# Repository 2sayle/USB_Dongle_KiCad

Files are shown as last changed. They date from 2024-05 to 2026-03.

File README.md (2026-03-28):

# USB Dongle (KiCad project)

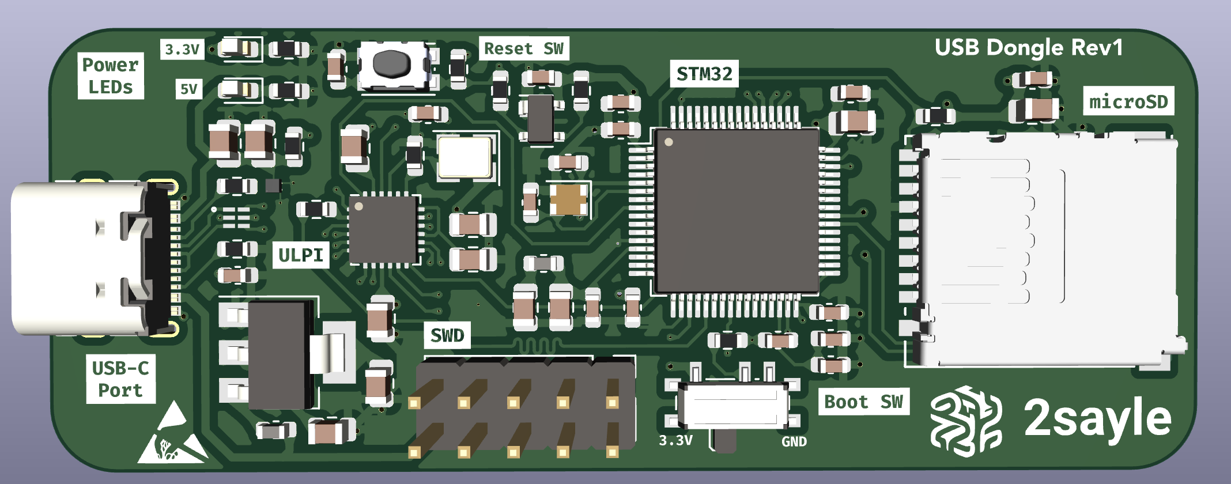
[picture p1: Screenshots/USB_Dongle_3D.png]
PCB view


KiCad project to create a custom USB-C key with mass storage and a microSD connector.
Find all the KiCad schematics and layout files.
Libraries containing custom footprints and symbols are available in ./Libraries folder.

## Hardware

- USB-C connector
- USB 2.0 High Speed Interface (through ULPI)
- STM32F730R8T microcontroller
- MicroSD connector
- Power LEDs
- GPIOs for SWD (Serial Wire Debug)

## Requirements

List any software requirements or dependencies needed to use or modify the project. For a KiCad project, this would include:

- KiCad EDA Suite version 7.0.2

## Installation

```
git clone https://github.com/2sayle/USB_Dongle_KiCad.git
```

## Usage

Explain how to use the project, with examples and screenshots if applicable.

## Documentation

Links to additional documentation for the project, such as a user manual or technical specifications.
- [STM32F730 Reference Manual](https://www.st.com/resource/en/reference_manual/rm0431-stm32f72xxx-and-stm32f73xxx-advanced-armbased-32bit-mcus-stmicroelectronics.pdf)
- [STM32F730R8 Datasheet](https://www.st.com/resource/en/datasheet/stm32f730i8.pdf)
- [ULPI Interface](http://ww1.microchip.com/downloads/en/DeviceDoc/334x.pdf)
- [USB ESD Protection](https://www.st.com/resource/en/datasheet/usbulc6-2m6.pdf)

Note: Datasheets are also available by selecting a component and pressing 'D' key, in KiCad schematics editor.

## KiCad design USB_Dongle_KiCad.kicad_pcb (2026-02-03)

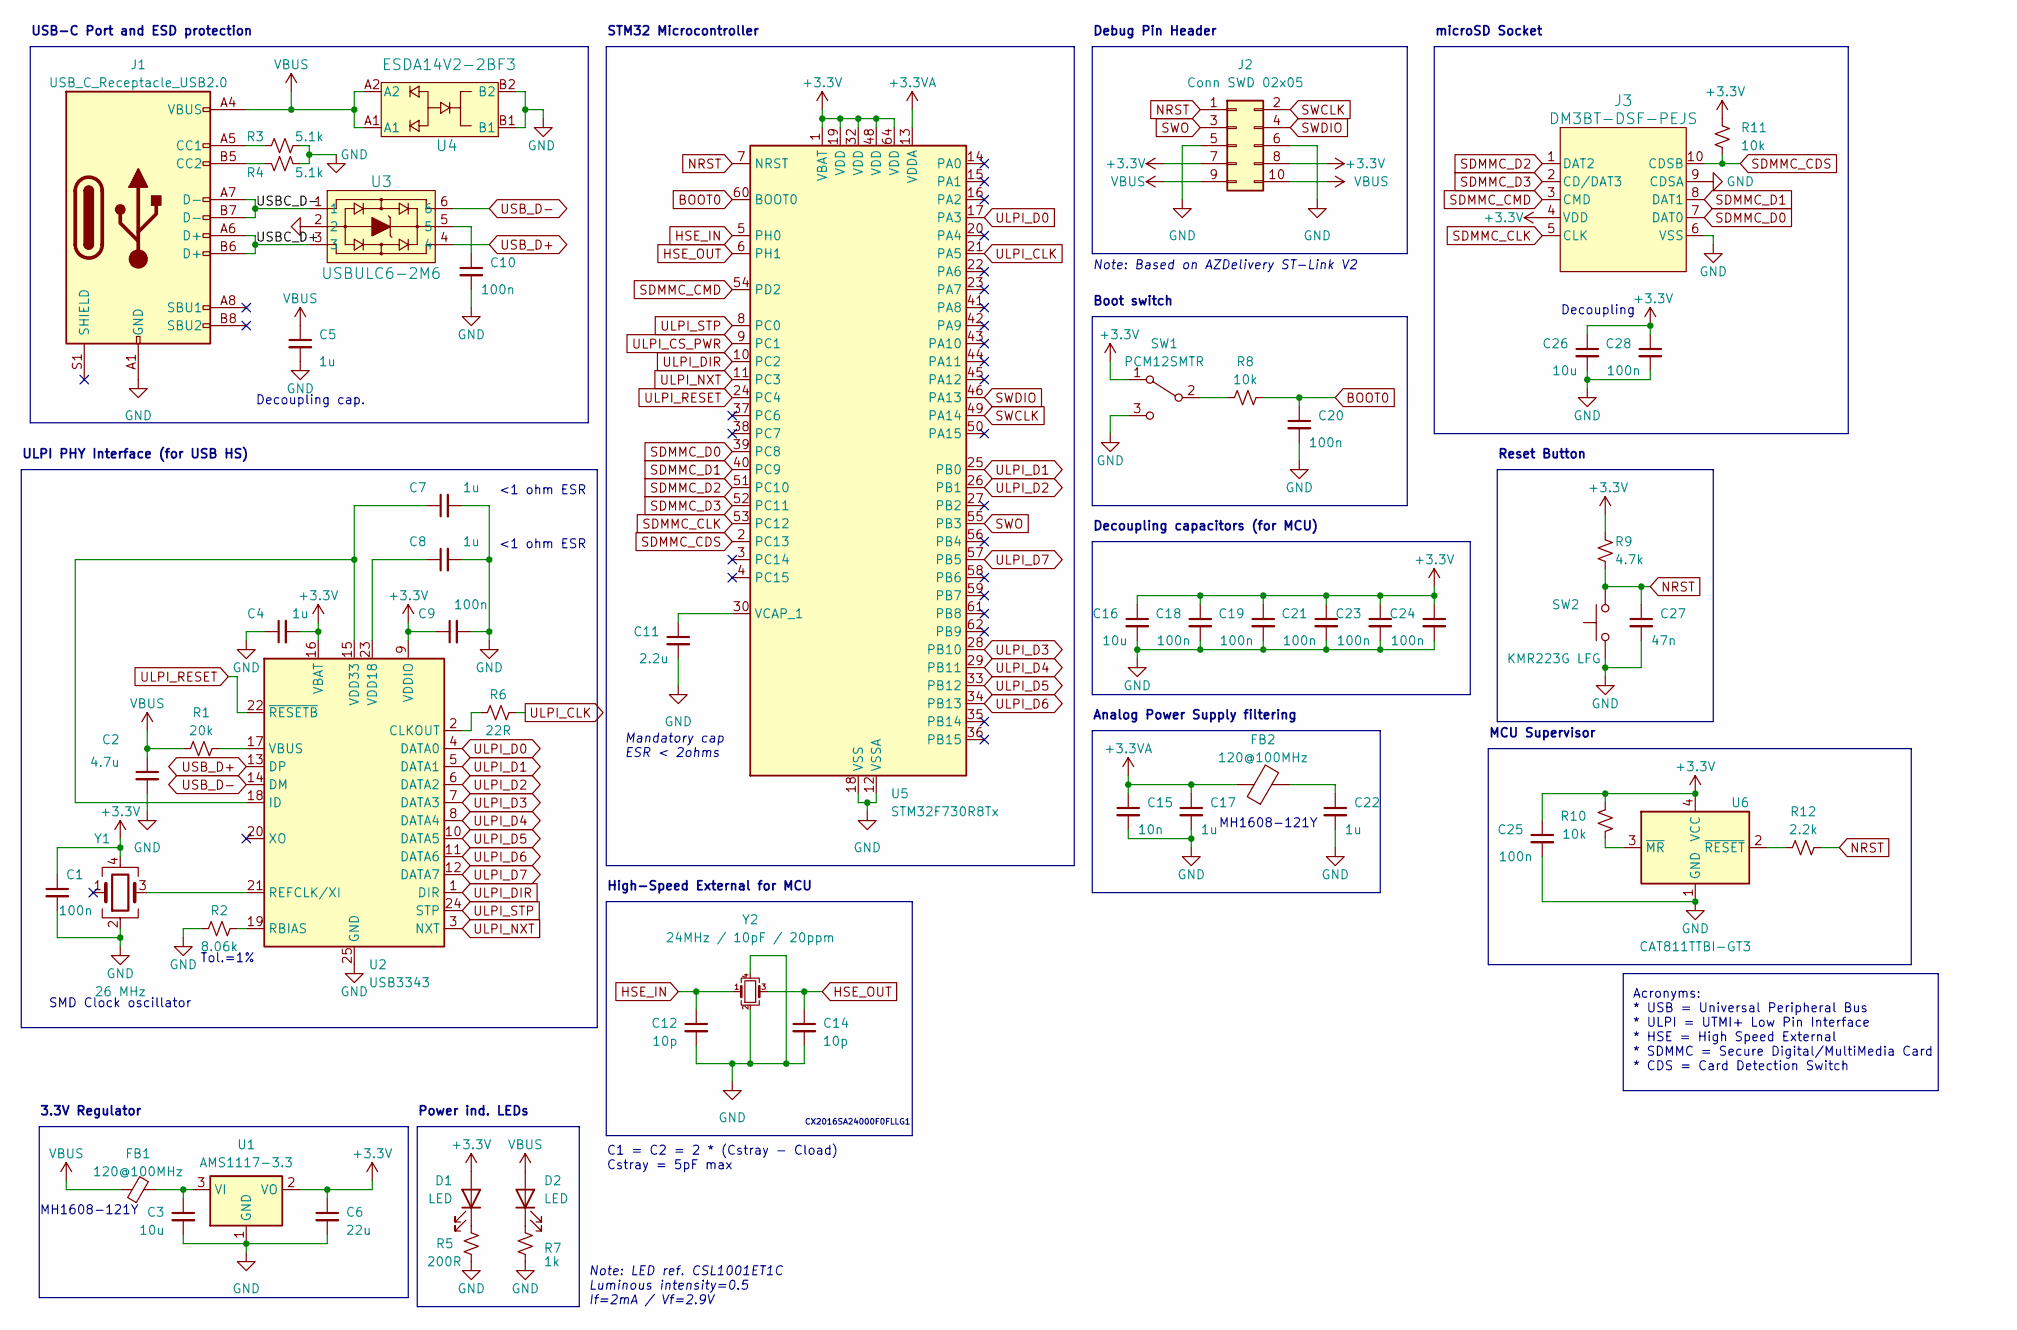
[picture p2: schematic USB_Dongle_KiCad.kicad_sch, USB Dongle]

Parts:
C1, C10, C18, C19, C20, C21, C23, C24, C25, C28: 100n; C_0603_1608Metric
C2: 4.7u; C_0805_2012Metric
C3, C16, C26: 10u; C_0805_2012Metric
C4, C5, C7, C8, C17, C22: 1u; C_0805_2012Metric
C6: 22u; C_0805_2012Metric
C9: 100n; C_0805_2012Metric
C11: 2.2u; C_0603_1608Metric
C12, C14: 10p; C_0603_1608Metric
C15: 10n; C_0603_1608Metric
C27: 47n; C_0603_1608Metric
D1, D2: LED; LED_0603_1608Metric
FB1, FB2: 120@100MHz; L_0603_1608Metric
J1: USB_C_Receptacle_USB2.0; USB_C_Receptacle_GCT_USB4105-xx-A_16P_TopMnt_Horizontal
J2: Conn SWD 02x05; PinHeader_2x05_P2.54mm_Vertical
J3: DM3BT-DSF-PEJS; DM3BT-DSF-PEJS_HIR
R1: 20k; R_0603_1608Metric
R2: 8.06k; R_0603_1608Metric
R3, R4: 5.1k; R_0603_1608Metric
R5: 200R; R_0603_1608Metric
R6: 22R; R_0603_1608Metric
R7: 1k; R_0603_1608Metric
R8, R10, R11: 10k; R_0603_1608Metric
R9: 4.7k; R_0603_1608Metric
R12: 2.2k; R_0603_1608Metric
SW1: PCM12SMTR; SW_SPDT_PCM12
SW2: KMR223G LFG; SW_Push_1P1T_NO_CK_KMR2
U1: AMS1117-3.3; SOT-223-3_TabPin2
U2: USB3343; QFN-24-1EP_4x4mm_P0.5mm_EP2.6x2.6mm
U3: USBULC6-2M6; MICROQFN6_1P45X1_STM
U4: ESDA14V2-2BF3; BGA_4V2-2BF3_STM
U5: STM32F730R8Tx; LQFP-64_10x10mm_P0.5mm
U6: CAT811TTBI-GT3; SOT-143
Y1: 26 MHz; Crystal_SMD_3225-4Pin_3.2x2.5mm
Y2: 24MHz / 10pF / 20ppm; Crystal_SMD_2016-4Pin_2.0x1.6mm

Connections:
+3.3V: C1.1, C4.2, C6.1, C9.1, C16.1, C18.1, C19.1, C21.1, C23.1, C24.1, C25.1, C26.1, C28.1, D1.2 (A), J2.7, J2.8, J3.4 (VDD), R9.1, R10.1, R11.2, SW1.1 (A), U1.2 (VO), U2.9 (VDDIO), U2.16 (VBAT), U5.1 (VBAT), U5.19 (VDD), U5.32 (VDD), U5.48 (VDD), U5.64 (VDD), U6.4 (VCC), Y1.4
+3.3VA: C15.1, C17.1, FB2.1, U5.13 (VDDA)
/USBC_D+: J1.A6 (D+), J1.B6 (D+), U3.3
/USBC_D-: J1.A7 (D-), J1.B7 (D-), U3.1
BOOT0: C20.1, R8.2, U5.60 (BOOT0)
GND: C1.2, C2.2, C3.2, C4.1, C5.2, C6.2, C7.2, C8.2, C9.2, C10.2, C11.2, C12.2, C14.2, C15.2, C16.2, C17.2, C18.2, C19.2, C20.2, C21.2, C22.2, C23.2, C24.2, C25.2, C26.2, C27.2, C28.2, J1.A1 (GND), J1.A12 (GND), J1.B1 (GND), J1.B12 (GND), J2.5, J2.6, J3.6 (VSS), J3.9 (CDSA), R2.1, R3.2, R4.2, R5.2, R7.2, SW1.3 (C), SW2.1, U1.1 (GND), U2.25 (GND), U3.2, U4.B1, U4.B2, U5.12 (VSSA), U5.18 (VSS), U5.31 (VSS), U5.47 (VSS), U5.63 (VSS), U6.1 (GND), Y1.2, Y2.2, Y2.4
HSE_IN: C12.1, U5.5 (PH0), Y2.1
HSE_OUT: C14.1, U5.6 (PH1), Y2.3
NRST: C27.1, J2.1, R9.2, R12.2, SW2.2, U5.7 (NRST)
unnamed: C10.1, U3.5
unnamed: C22.1, FB2.2
unnamed: D1.1 (K), R5.1
unnamed: D2.1 (K), R7.1
unnamed: J1.A5 (CC1), R3.1
unnamed: J1.B5 (CC2), R4.1
unnamed: R8.1, SW1.2 (B)
unnamed: C3.1, FB1.2, U1.3 (VI)
unnamed: R6.1, U2.2 (CLKOUT)
unnamed: C7.1, U2.15 (VDD33), U2.18 (ID)
unnamed: R2.2, U2.19 (RBIAS)
unnamed: U2.21 (REFCLK/XI), Y1.3
unnamed: R1.2, U2.17 (VBUS)
unnamed: C8.1, U2.23 (VDD18)
unnamed: C11.1, U5.30 (VCAP_1)
unnamed: R10.2, U6.3 (~MR)
unnamed: R12.1, U6.2 (~RESET)
SDMMC_CDS: J3.10 (CDSB), R11.1, U5.2 (PC13)
SDMMC_CLK: J3.5 (CLK), U5.53 (PC12)
SDMMC_CMD: J3.3 (CMD), U5.54 (PD2)
SDMMC_D0: J3.7 (DAT0), U5.39 (PC8)
SDMMC_D1: J3.8 (DAT1), U5.40 (PC9)
SDMMC_D2: J3.1 (DAT2), U5.51 (PC10)
SDMMC_D3: J3.2 (CD/DAT3), U5.52 (PC11)
SWCLK: J2.2, U5.49 (PA14)
SWDIO: J2.4, U5.46 (PA13)
SWO: J2.3, U5.55 (PB3)
ULPI_CLK: R6.2, U5.21 (PA5)
ULPI_CS_PWR: U5.9 (PC1)
ULPI_D0: U2.4 (DATA0), U5.17 (PA3)
ULPI_D1: U2.5 (DATA1), U5.25 (PB0)
ULPI_D2: U2.6 (DATA2), U5.26 (PB1)
ULPI_D3: U2.7 (DATA3), U5.28 (PB10)
ULPI_D4: U2.8 (DATA4), U5.29 (PB11)
ULPI_D5: U2.10 (DATA5), U5.33 (PB12)
ULPI_D6: U2.11 (DATA6), U5.34 (PB13)
ULPI_D7: U2.12 (DATA7), U5.57 (PB5)
ULPI_DIR: U2.1 (DIR), U5.10 (PC2)
ULPI_NXT: U2.3 (NXT), U5.11 (PC3)
ULPI_RESET: U2.22 (~RESETB), U5.24 (PC4)
ULPI_STP: U2.24 (STP), U5.8 (PC0)
USB_D+: U2.13 (DP), U3.4
USB_D-: U2.14 (DM), U3.6
VBUS: C2.1, C5.1, D2.2 (A), FB1.1, J1.A4 (VBUS), J1.A9 (VBUS), J1.B4 (VBUS), J1.B9 (VBUS), J2.9, J2.10, R1.1, U4.A1, U4.A2

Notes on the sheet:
Decoupling
USB-C Port and ESD protection
Reset Button
Decoupling capacitors (for MCU)
Note: LED ref. CSL1001ET1C Luminous intensity=0.5 If=2mA / Vf=2.9V
Tol.=1%
MH1608-121Y
Decoupling cap.
MCU Supervisor
3.3V Regulator
Analog Power Supply filtering
<1 ohm ESR
High-Speed External for MCU
Note: Based on AZDelivery ST-Link V2
Mandatory cap ESR < 2ohms
CX2016SA24000F0FLLG1
SMD Clock oscillator
microSD Socket
C1 = C2 = 2 * (Cstray - Cload) Cstray = 5pF max
Debug Pin Header
Power ind. LEDs
ULPI PHY Interface (for USB HS)
STM32 Microcontroller
Acronyms: * USB = Universal Peripheral Bus * ULPI = UTMI+ Low Pin Interface * HSE = High Speed External * SDMMC = Secure Digital/MultiMedia Card * CDS = Card Detection Switch
Boot switch

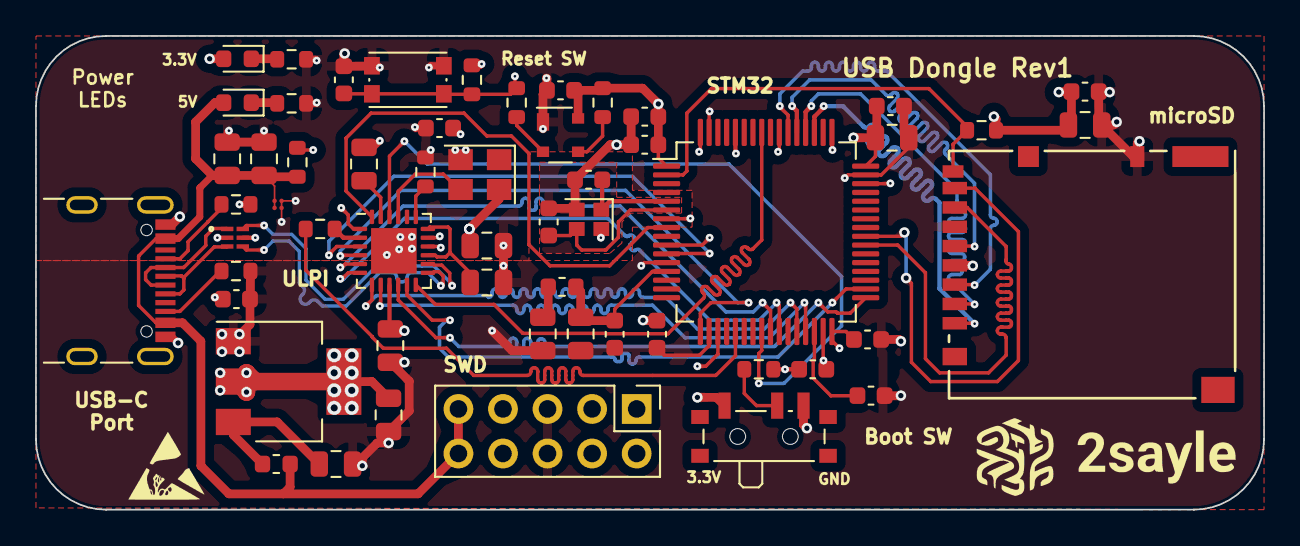
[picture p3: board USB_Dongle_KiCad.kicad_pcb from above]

Board: 6 copper layers, 70.0 x 27.0 mm, 56 parts (0 on the bottom side), 52 nets.

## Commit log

2024-05-02 Added project files
    [USB_Dongle_KiCad.kicad_pcb, USB_Dongle_KiCad.kicad_sch]
2024-05-02 Tiny updates in the schematics
    [USB_Dongle_KiCad.kicad_sch]
2024-05-02 Added: New microSD component
    [USB_Dongle_KiCad.kicad_sch]
2024-05-03 Added: Clock oscillator for ULPI
    [USB_Dongle_KiCad.kicad_sch]
2024-05-03 Added: Pull-down resistors for CCx pins (USB-C port)
    [USB_Dongle_KiCad.kicad_sch]
2024-05-03 Executed DRC and ignored irrelevant warnings
    [USB_Dongle_KiCad.kicad_sch]
2024-05-03 Assigned footprints to symbols
    [USB_Dongle_KiCad.kicad_sch]
2024-05-03 Created layout
    [USB_Dongle_KiCad.kicad_pcb, USB_Dongle_KiCad.kicad_sch]
2024-05-04 Updated: PCB design rules
    [USB_Dongle_KiCad.kicad_pcb]
2024-05-04 Update: Routing of high speed tracks
    [USB_Dongle_KiCad.kicad_pcb, USB_Dongle_KiCad.kicad_sch]
2024-05-05 Update: near end of layout
    [USB_Dongle_KiCad.kicad_pcb]
2024-05-05 Various fixes and other 3D models added
    [USB_Dongle_KiCad.kicad_pcb]
2024-05-15 Update: New routing after ULPI component change
    [USB_Dongle_KiCad.kicad_pcb, USB_Dongle_KiCad.kicad_sch]
2024-05-17 Improved layout
    [USB_Dongle_KiCad.kicad_pcb]
2024-05-18 Added: 3D screenshot
    [USB_Dongle_KiCad.kicad_pcb]
2024-06-29 Small changes
    [USB_Dongle_KiCad.kicad_pcb]
2026-02-03 Fix: Value of external capacitor for VCAP1
    [USB_Dongle_KiCad.kicad_pcb, USB_Dongle_KiCad.kicad_sch]
2026-03-28 Add PCB view image to README
    Added a PCB view image to the README.
